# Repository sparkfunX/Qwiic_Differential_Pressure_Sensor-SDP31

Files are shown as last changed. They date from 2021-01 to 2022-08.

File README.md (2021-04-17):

SparkX Differential Pressure Sensor - SDP31 (Qwiic)
===================================================

SparkX Qwiic Differential Pressure Sensor SDP31 (SPX-17874) (https://www.sparkfun.com/products/17874)

[*SparkX Differential Pressure Sensor - SDP31 (Qwiic) (SPX-17874)*](https://www.sparkfun.com/products/17874)

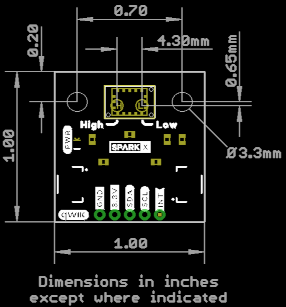
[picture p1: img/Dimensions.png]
SparkX Differential Pressure Sensor - SDP31


The SDP3x sensor family is Sensirion’s series of small differential pressure sensors designed for high-volume applications
where size is a key requirement. It builds on the next generation CMOSens® sensor chip that is at the heart of Sensirion’s
new differential pressure and flow sensing platform.

The digital SDP31 sensor features fast measurement speed, excellent accuracy and long-term stability and has no zero-point
drift. Furthermore, it is reflow solderable and provides extended functionality, such as smart averaging, multiple temperature
compensation modes, configurable I2C address and interrupts.

Able to measure differential pressures in the range +/- 500 Pascals (+/- 0.005 Atm), the SDP31 is ideally suited to air flow rate
and air speed measurement. Need an air speed indicator for your drone or model aircraft? This could be the sensor for you!

Repository Contents
-------------------
* **/Documents** - datasheets etc.
* **/Hardware** - Eagle design files (.brd, .sch)

Documentation
--------------
* **[SDP3X Arduino Library](https://github.com/sparkfun/SparkFun_SDP3x_Arduino_Library)** - Arduino library for the SparkFun Differential Pressure Sensor - SDP31.
* **[Hookup Guide]()** - Basic hookup guide for the SparkX Differential Pressure Sensor - SDP31.

Product Versions
----------------
* [SPX-17874](https://www.sparkfun.com/products/17874) - Original SparkX Release.

License Information
-------------------

This product is _**open source**_!

Please review the LICENSE.md file for license information.

If you have any questions or concerns on licensing, please contact technical support on our [SparkFun forums](https://forum.sparkfun.com/viewforum.php?f=152).

Distributed as-is; no warranty is given.

- Your friends at SparkFun.

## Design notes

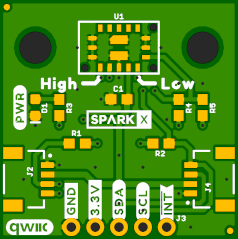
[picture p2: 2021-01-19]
img/Top.png

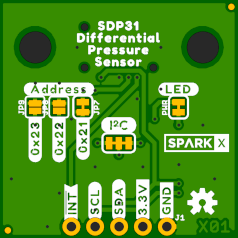
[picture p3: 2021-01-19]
img/Bottom.png

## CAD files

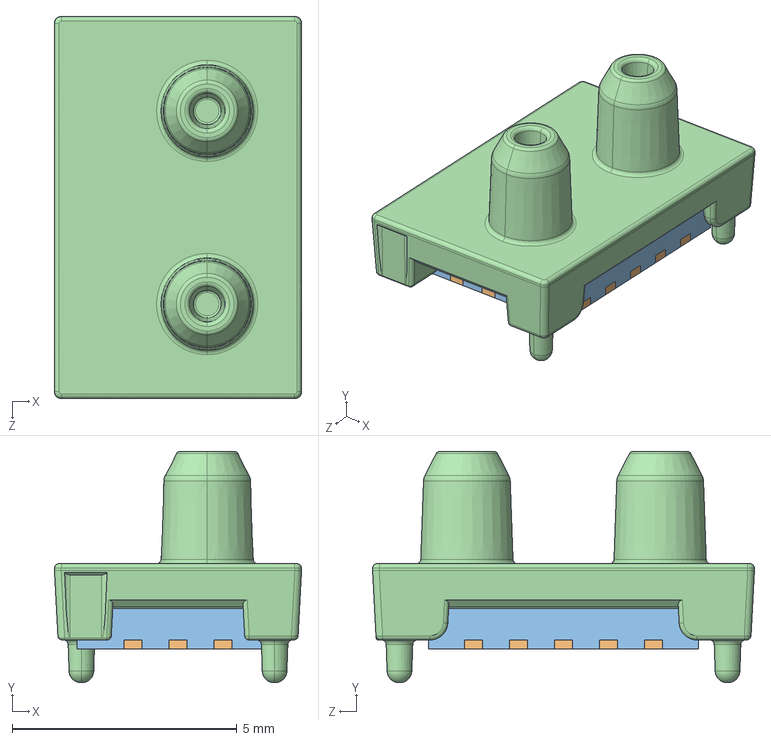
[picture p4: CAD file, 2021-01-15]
Documents/Sensirion_Differential_Pressure_Sensors_SDP3x_STEP_file.step
5.50 x 5.15 x 8.50 mm

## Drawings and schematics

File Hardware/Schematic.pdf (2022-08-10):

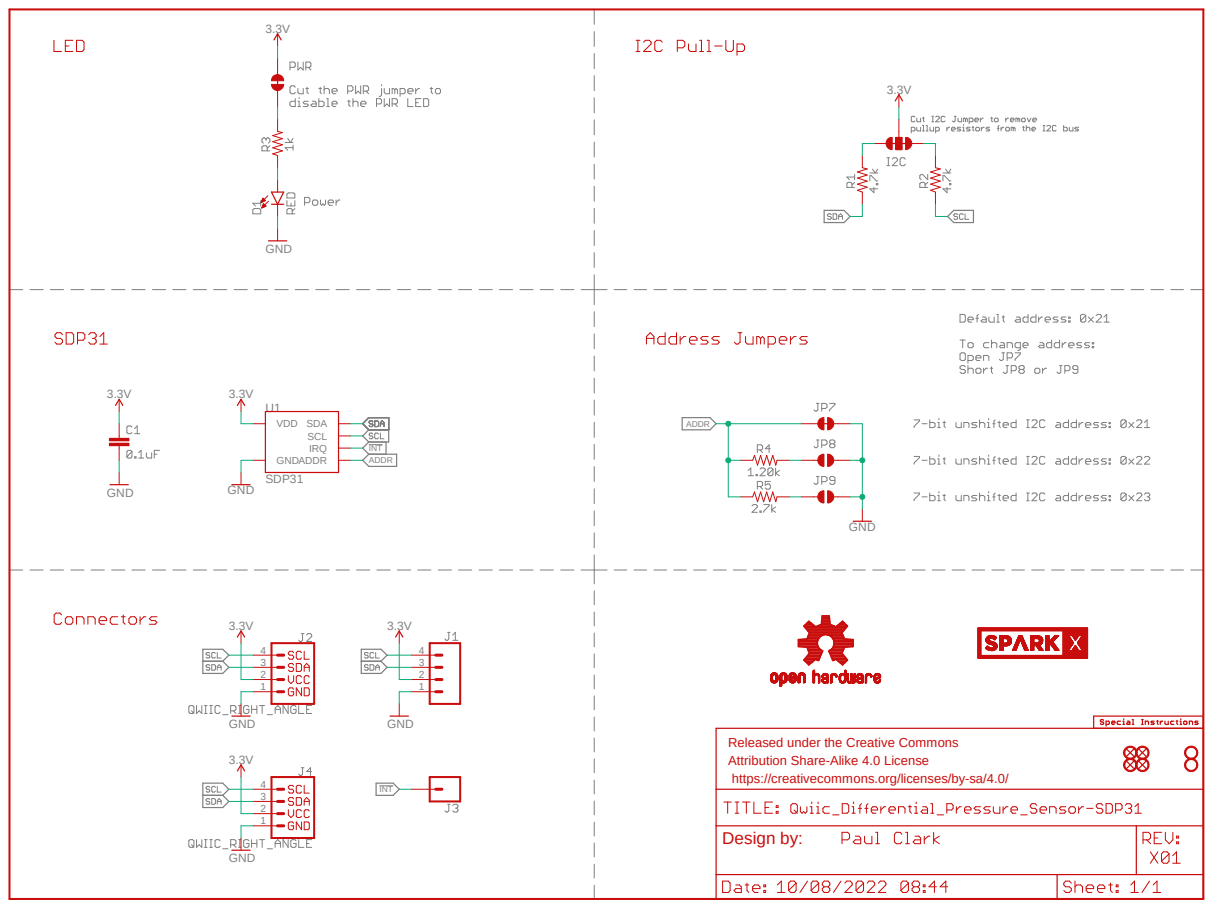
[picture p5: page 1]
GND; SDP31; VDD; SDA SCL IRQ; ADDR U1; INT; ADDR; Design by:

Released under the Creative Commons
Attribution Share-Alike 4.0 License
https://creativecommons.org/licenses/by-sa/4.0/

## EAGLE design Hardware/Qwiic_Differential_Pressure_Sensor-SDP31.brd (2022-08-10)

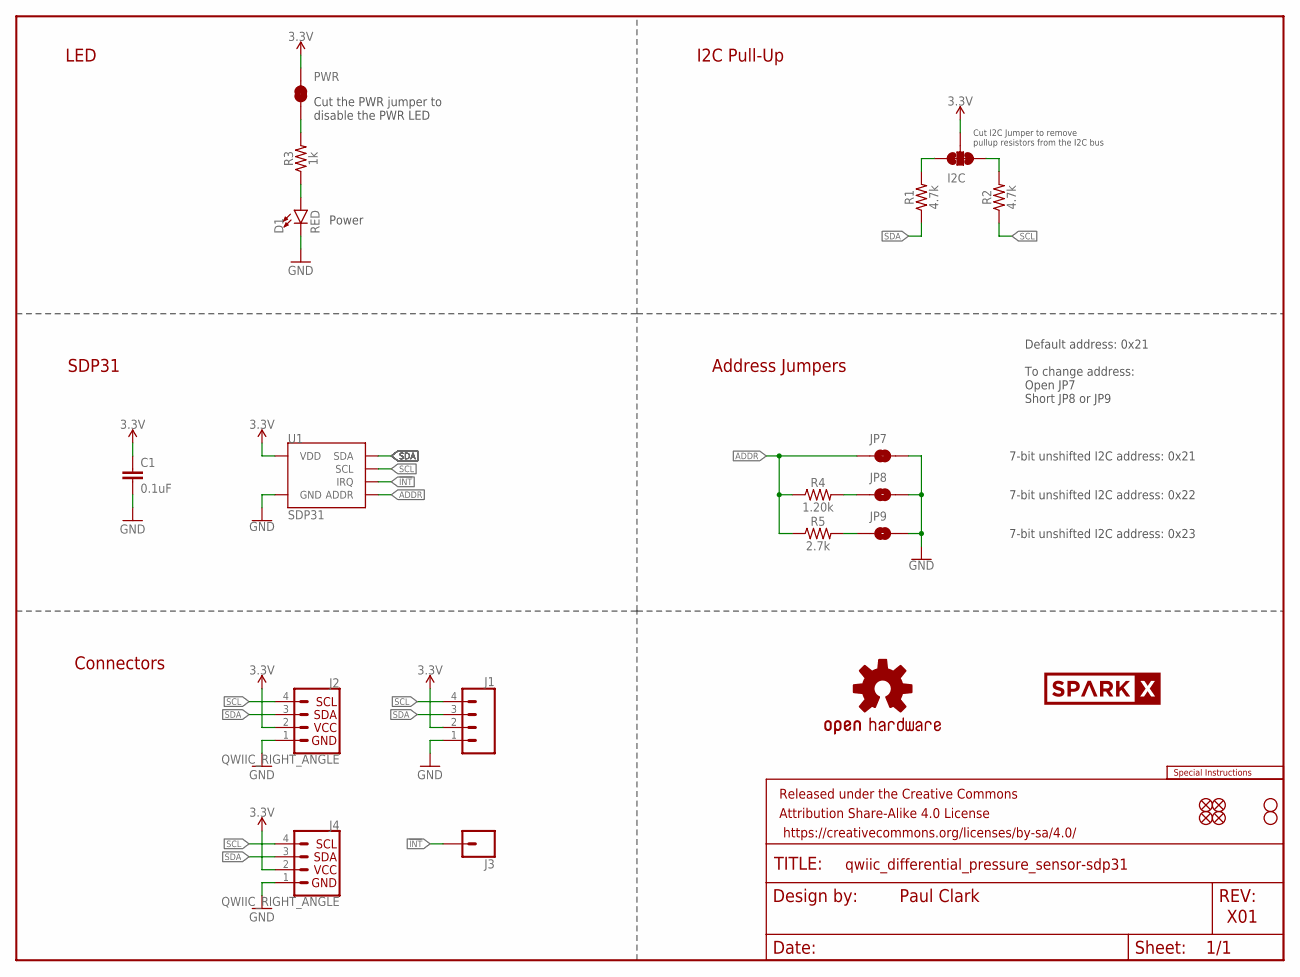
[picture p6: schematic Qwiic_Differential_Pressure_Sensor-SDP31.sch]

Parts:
C1: 0.1uF; 0603
D1: RED; LED-0603
FRAME1: FRAME-LETTER; CREATIVE_COMMONS
I2C: JUMPER-SMT_3_2-NC_TRACE_SILK; SMT-JUMPER_3_2-NC_TRACE_SILK
J1: CONN_041X04_NO_SILK; 1X04_NO_SILK
J2, J4: QWIIC_RIGHT_ANGLE; JST04_1MM_RA
J3: CONN_01PTH_NO_SILK_YES_STOP; 1X01_NO_SILK
JP1, JP2, JP5, JP6: FIDUCIALUFIDUCIAL; FIDUCIAL-MICRO
JP3, JP4: STAND-OFF
JP7: JUMPER-SMT_2_NC_TRACE_SILK; SMT-JUMPER_2_NC_TRACE_SILK
JP8, JP9: JUMPER-SMT_2_NO_SILK; SMT-JUMPER_2_NO_SILK
LOGO1: SPECIAL_INSTRUCTIONS-ORDERING; ORDERING_INSTRUCTIONS
LOGO5: OSHW-LOGOS; OSHW-LOGO-S
PWR: JUMPER-SMT_2_NC_TRACE_SILK; SMT-JUMPER_2_NC_TRACE_SILK
R1, R2: 4.7k; 0603
R3: 1k; 0603
R4: 1.20k; 0603
R5: 2.7k; 0603
U1: SDP31; SDP3X
U$18: SPARKX-LOGO3; SPARKX-SMALL

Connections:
3.3V: C1.1, I2C.2, J1.2, J2.2, J4.2, PWR.2, U1.7 (VDD)
!INT!: J3.1, U1.4 (IRQ)
ADDR: JP7.1, R4.1, R5.1, U1.9 (ADDR)
GND: C1.2, D1.C, J1.1, J2.1, J4.1, JP7.2, JP8.2, JP9.2, U1.1 (GND), U1.2 (GND), U1.3 (GND), U1.6 (GND), U1.10 (GND), U1.11 (GND), U1.DIEPAD1 (GND), U1.DIEPAD2 (GND)
unnamed: PWR.1, R3.2
unnamed: I2C.3, R1.2
unnamed: D1.A, R3.1
unnamed: I2C.1, R2.2
unnamed: JP8.1, R4.2
unnamed: JP9.1, R5.2
SCL: J1.4, J2.4, J4.4, R2.1, U1.5 (SCL)
SDA: J1.3, J2.3, J4.3, R1.1, U1.8 (SDA)

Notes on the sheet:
Paul Clark
X01
7-bit unshifted I2C address: 0x21
Power
I2C Pull-Up
SDP31
Connectors
Cut the PWR jumper to disable the PWR LED
Cut I2C Jumper to remove pullup resistors from the I2C bus
LED
Address Jumpers
7-bit unshifted I2C address: 0x22
7-bit unshifted I2C address: 0x23
Default address: 0x21 To change address: Open JP7 Short JP8 or JP9

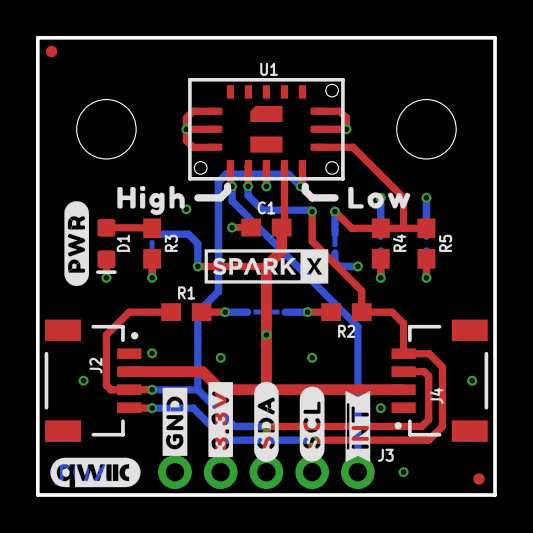
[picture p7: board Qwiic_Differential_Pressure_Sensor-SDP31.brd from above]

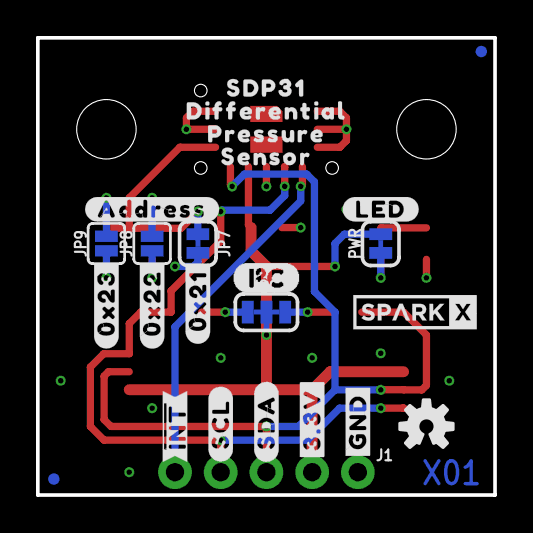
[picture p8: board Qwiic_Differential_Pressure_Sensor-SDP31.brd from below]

Board: 4 copper layers, 25.4 x 25.4 mm, 52 parts (25 on the bottom side), 12 nets.

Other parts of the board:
U$1, U$33: #GND#0
U$2, U$34: #3#3V#0
U$3, U$35: #SDA#0
U$4, U$36: #SCL#0
U$5, U$6: ##INT##0
U$7: #0X21#0
U$8: #0X22#0
U$9: #0X23#0
U$10: DIFFERENTIAL0
U$11: PRESSURE0
U$12: SENSOR0
U$13: SDP310
U$14: #LED#0
U$15: I2C
U$16: QWIIC_5MM
U$17: HIGH0
U$19: LOW0
U$20: SPARKX-LOGO3; SPARKX-SMALL
U$21: #ADDRESS#0
U$32: #PWR#0

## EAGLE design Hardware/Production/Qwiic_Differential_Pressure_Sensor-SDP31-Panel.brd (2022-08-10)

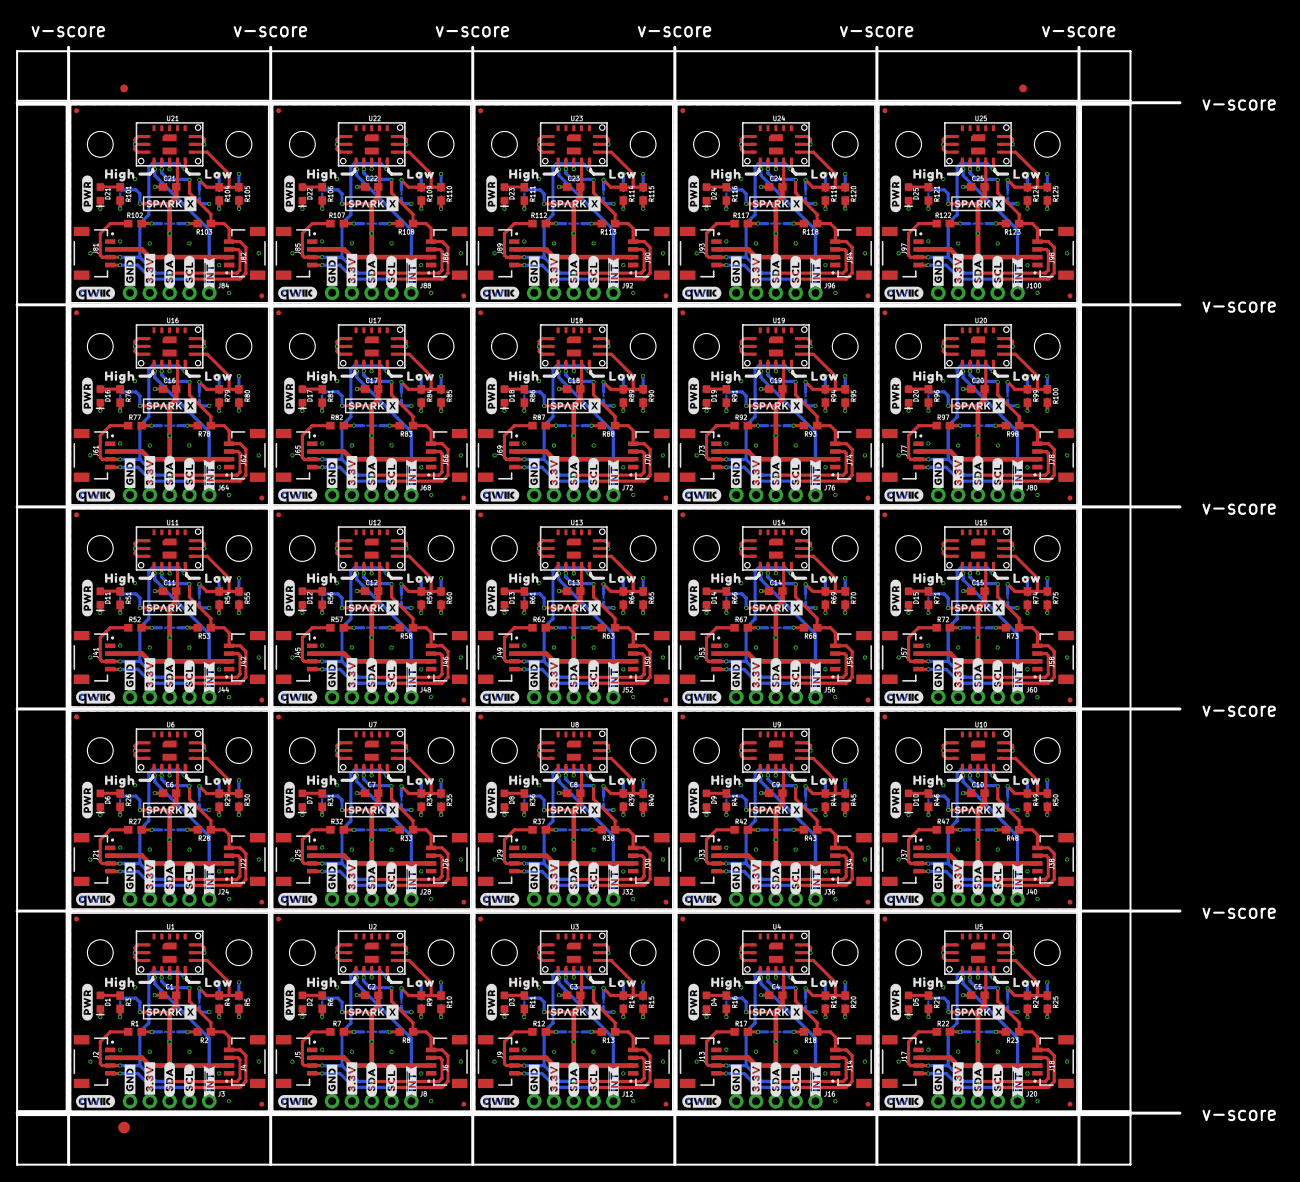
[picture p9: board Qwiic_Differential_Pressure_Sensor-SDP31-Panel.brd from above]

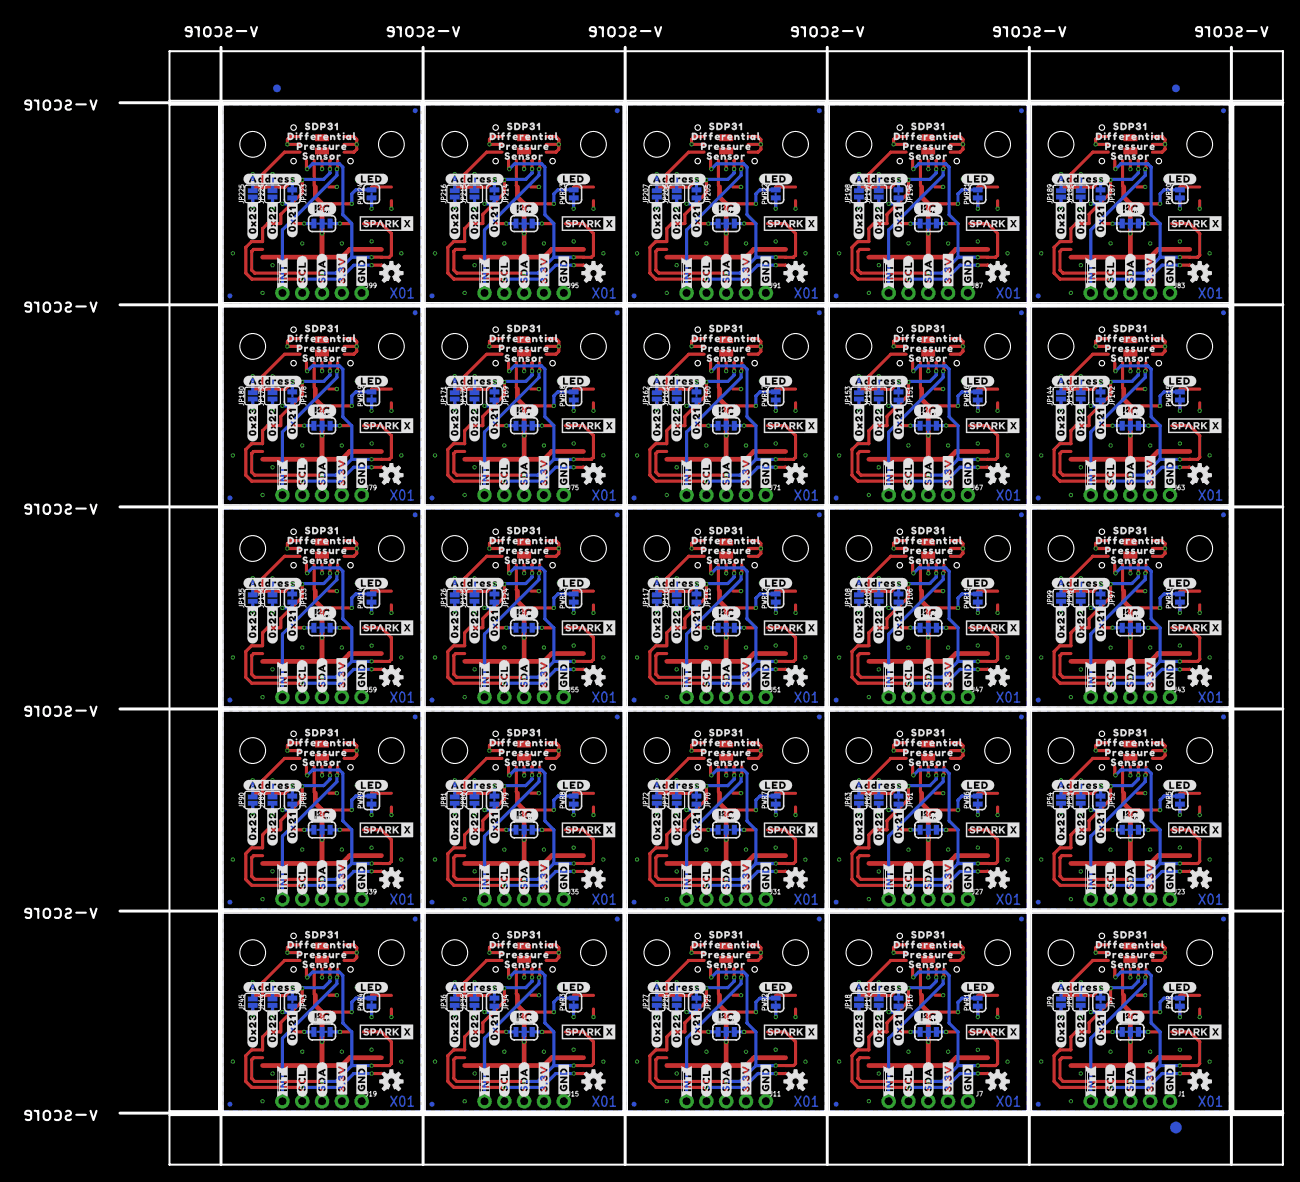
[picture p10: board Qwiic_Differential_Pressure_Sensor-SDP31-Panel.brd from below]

Board: 4 copper layers, 149.1 x 143.3 mm, 1256 parts (628 on the bottom side), 300 nets.

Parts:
C1, C2, C3, C4, C5, C6, C7, C8, C9, C10, C11, C12, C13, C14, C15, C16, C17, C18, C19, C20, C21, C22, C23, C24, C25: 0.1uF; 0603
D1, D2, D3, D4, D5, D6, D7, D8, D9, D10, D11, D12, D13, D14, D15, D16, D17, D18, D19, D20, D21, D22, D23, D24, D25: RED; LED-0603
E$1, E$2, E$3, E$4: FIDUCIAL-1X2
E$5, E$6: FIDUCIAL-1.5X3
I2C, I2C1, I2C2, I2C3, I2C4, I2C5, I2C6, I2C7, I2C8, I2C9, I2C10, I2C11, I2C12, I2C13, I2C14, I2C15, I2C16, I2C17, I2C18, I2C19, I2C20, I2C21, I2C22, I2C23, I2C24: JUMPER-SMT_3_2-NC_TRACE_SILK; SMT-JUMPER_3_2-NC_TRACE_SILK
J1, J7, J11, J15, J19, J23, J27, J31, J35, J39, J43, J47, J51, J55, J59, J63, J67, J71, J75, J79, J83, J87, J91, J95, J99: 1X04_NO_SILK
J2, J4, J5, J6, J9, J10, J13, J14, J17, J18, J21, J22, J25, J26, J29, J30, J33, J34, J37, J38, J41, J42, J45, J46, J49, J50, J53, J54, J57, J58, J61, J62, J65, J66, J69, J70, J73, J74, J77, J78, J81, J82, J85, J86, J89, J90, J93, J94, J97, J98: QWIIC_RIGHT_ANGLE; JST04_1MM_RA
J3, J8, J12, J16, J20, J24, J28, J32, J36, J40, J44, J48, J52, J56, J60, J64, J68, J72, J76, J80, J84, J88, J92, J96, J100: 1X01_NO_SILK
JP1, JP2, JP5, JP6, JP12, JP13, JP14, JP15, JP21, JP22, JP23, JP24, JP30, JP31, JP32, JP33, JP39, JP40, JP41, JP42, JP48, JP49, JP50, JP51, JP57, JP58, JP59, JP60, JP66, JP67, JP68, JP69, JP75, JP76, JP77, JP78, JP84, JP85, JP86, JP87, JP93, JP94, JP95, JP96, JP102, JP103, JP104, JP105, JP111, JP112, JP113, JP114, JP120, JP121, JP122, JP123, JP129, JP130, JP131, JP132, JP138, JP139, JP140, JP141, JP147, JP148, JP149, JP150, JP156, JP157, JP158, JP159, JP165, JP166, JP167, JP168, JP174, JP175, JP176, JP177, JP183, JP184, JP185, JP186, JP192, JP193, JP194, JP195, JP201, JP202, JP203, JP204, JP210, JP211, JP212, JP213, JP219, JP220, JP221, JP222: FIDUCIALUFIDUCIAL; FIDUCIAL-MICRO
JP3, JP4, JP10, JP11, JP19, JP20, JP28, JP29, JP37, JP38, JP46, JP47, JP55, JP56, JP64, JP65, JP73, JP74, JP82, JP83, JP91, JP92, JP100, JP101, JP109, JP110, JP118, JP119, JP127, JP128, JP136, JP137, JP145, JP146, JP154, JP155, JP163, JP164, JP172, JP173, JP181, JP182, JP190, JP191, JP199, JP200, JP208, JP209, JP217, JP218: STAND-OFF
JP7, JP16, JP25, JP34, JP43, JP52, JP61, JP70, JP79, JP88, JP97, JP106, JP115, JP124, JP133, JP142, JP151, JP160, JP169, JP178, JP187, JP196, JP205, JP214, JP223: JUMPER-SMT_2_NC_TRACE_SILK; SMT-JUMPER_2_NC_TRACE_SILK
JP8, JP9, JP17, JP18, JP26, JP27, JP35, JP36, JP44, JP45, JP53, JP54, JP62, JP63, JP71, JP72, JP80, JP81, JP89, JP90, JP98, JP99, JP107, JP108, JP116, JP117, JP125, JP126, JP134, JP135, JP143, JP144, JP152, JP153, JP161, JP162, JP170, JP171, JP179, JP180, JP188, JP189, JP197, JP198, JP206, JP207, JP215, JP216, JP224, JP225: JUMPER-SMT_2_NO_SILK; SMT-JUMPER_2_NO_SILK
LOGO1, LOGO2, LOGO3, LOGO4, LOGO5, LOGO6, LOGO7, LOGO8, LOGO9, LOGO10, LOGO11, LOGO12, LOGO13, LOGO14, LOGO15, LOGO16, LOGO17, LOGO18, LOGO19, LOGO20, LOGO21, LOGO22, LOGO23, LOGO24, LOGO25: OSHW-LOGOS; OSHW-LOGO-S
PWR, PWR1, PWR2, PWR3, PWR4, PWR5, PWR6, PWR7, PWR8, PWR9, PWR10, PWR11, PWR12, PWR13, PWR14, PWR15, PWR16, PWR17, PWR18, PWR19, PWR20, PWR21, PWR22, PWR23, PWR24: JUMPER-SMT_2_NC_TRACE_SILK; SMT-JUMPER_2_NC_TRACE_SILK
R1, R2, R7, R8, R12, R13, R17, R18, R22, R23, R27, R28, R32, R33, R37, R38, R42, R43, R47, R48, R52, R53, R57, R58, R62, R63, R67, R68, R72, R73, R77, R78, R82, R83, R87, R88, R92, R93, R97, R98, R102, R103, R107, R108, R112, R113, R117, R118, R122, R123: 4.7k; 0603
R3, R6, R11, R16, R21, R26, R31, R36, R41, R46, R51, R56, R61, R66, R71, R76, R81, R86, R91, R96, R101, R106, R111, R116, R121: 1k; 0603
R4, R9, R14, R19, R24, R29, R34, R39, R44, R49, R54, R59, R64, R69, R74, R79, R84, R89, R94, R99, R104, R109, R114, R119, R124: 1.20k; 0603
R5, R10, R15, R20, R25, R30, R35, R40, R45, R50, R55, R60, R65, R70, R75, R80, R85, R90, R95, R100, R105, R110, R115, R120, R125: 2.7k; 0603
U1, U2, U3, U4, U5, U6, U7, U8, U9, U10, U11, U12, U13, U14, U15, U16, U17, U18, U19, U20, U21, U22, U23, U24, U25: SDP31; SDP3X
U$1, U$26, U$30, U$33, U$57, U$61, U$83, U$87, U$109, U$113, U$135, U$139, U$161, U$165, U$187, U$191, U$213, U$217, U$239, U$243, U$265, U$269, U$291, U$295, U$317, U$321, U$343, U$347, U$369, U$373, U$395, U$399, U$421, U$425, U$447, U$451, U$473, U$477, U$499, U$503, U$525, U$529, U$551, U$555, U$577, U$581, U$603, U$607, U$629, U$633: #GND#0
U$2, U$27, U$31, U$34, U$58, U$62, U$84, U$88, U$110, U$114, U$136, U$140, U$162, U$166, U$188, U$192, U$214, U$218, U$240, U$244, U$266, U$270, U$292, U$296, U$318, U$322, U$344, U$348, U$370, U$374, U$396, U$400, U$422, U$426, U$448, U$452, U$474, U$478, U$500, U$504, U$526, U$530, U$552, U$556, U$578, U$582, U$604, U$608, U$630, U$634: #3#3V#0
U$3, U$28, U$35, U$37, U$59, U$63, U$85, U$89, U$111, U$115, U$137, U$141, U$163, U$167, U$189, U$193, U$215, U$219, U$241, U$245, U$267, U$271, U$293, U$297, U$319, U$323, U$345, U$349, U$371, U$375, U$397, U$401, U$423, U$427, U$449, U$453, U$475, U$479, U$501, U$505, U$527, U$531, U$553, U$557, U$579, U$583, U$605, U$609, U$631, U$635: #SDA#0
U$4, U$29, U$36, U$38, U$60, U$64, U$86, U$90, U$112, U$116, U$138, U$142, U$164, U$168, U$190, U$194, U$216, U$220, U$242, U$246, U$268, U$272, U$294, U$298, U$320, U$324, U$346, U$350, U$372, U$376, U$398, U$402, U$424, U$428, U$450, U$454, U$476, U$480, U$502, U$506, U$528, U$532, U$554, U$558, U$580, U$584, U$606, U$610, U$632, U$636: #SCL#0
U$5, U$6, U$50, U$51, U$76, U$77, U$102, U$103, U$128, U$129, U$154, U$155, U$180, U$181, U$206, U$207, U$232, U$233, U$258, U$259, U$284, U$285, U$310, U$311, U$336, U$337, U$362, U$363, U$388, U$389, U$414, U$415, U$440, U$441, U$466, U$467, U$492, U$493, U$518, U$519, U$544, U$545, U$570, U$571, U$596, U$597, U$622, U$623, U$648, U$649: ##INT##0
U$7, U$39, U$65, U$91, U$117, U$143, U$169, U$195, U$221, U$247, U$273, U$299, U$325, U$351, U$377, U$403, U$429, U$455, U$481, U$507, U$533, U$559, U$585, U$611, U$637: #0X21#0
U$8, U$40, U$66, U$92, U$118, U$144, U$170, U$196, U$222, U$248, U$274, U$300, U$326, U$352, U$378, U$404, U$430, U$456, U$482, U$508, U$534, U$560, U$586, U$612, U$638: #0X22#0
U$9, U$41, U$67, U$93, U$119, U$145, U$171, U$197, U$223, U$249, U$275, U$301, U$327, U$353, U$379, U$405, U$431, U$457, U$483, U$509, U$535, U$561, U$587, U$613, U$639: #0X23#0
U$10, U$42, U$68, U$94, U$120, U$146, U$172, U$198, U$224, U$250, U$276, U$302, U$328, U$354, U$380, U$406, U$432, U$458, U$484, U$510, U$536, U$562, U$588, U$614, U$640: DIFFERENTIAL0
U$11, U$43, U$69, U$95, U$121, U$147, U$173, U$199, U$225, U$251, U$277, U$303, U$329, U$355, U$381, U$407, U$433, U$459, U$485, U$511, U$537, U$563, U$589, U$615, U$641: PRESSURE0
U$12, U$44, U$70, U$96, U$122, U$148, U$174, U$200, U$226, U$252, U$278, U$304, U$330, U$356, U$382, U$408, U$434, U$460, U$486, U$512, U$538, U$564, U$590, U$616, U$642: SENSOR0
U$13, U$45, U$71, U$97, U$123, U$149, U$175, U$201, U$227, U$253, U$279, U$305, U$331, U$357, U$383, U$409, U$435, U$461, U$487, U$513, U$539, U$565, U$591, U$617, U$643: SDP310
U$14, U$46, U$72, U$98, U$124, U$150, U$176, U$202, U$228, U$254, U$280, U$306, U$332, U$358, U$384, U$410, U$436, U$462, U$488, U$514, U$540, U$566, U$592, U$618, U$644: #LED#0
U$15, U$22, U$53, U$79, U$105, U$131, U$157, U$183, U$209, U$235, U$261, U$287, U$313, U$339, U$365, U$391, U$417, U$443, U$469, U$495, U$521, U$547, U$573, U$599, U$625: I2C
U$16, U$23, U$54, U$80, U$106, U$132, U$158, U$184, U$210, U$236, U$262, U$288, U$314, U$340, U$366, U$392, U$418, U$444, U$470, U$496, U$522, U$548, U$574, U$600, U$626: QWIIC_5MM
U$17, U$47, U$73, U$99, U$125, U$151, U$177, U$203, U$229, U$255, U$281, U$307, U$333, U$359, U$385, U$411, U$437, U$463, U$489, U$515, U$541, U$567, U$593, U$619, U$645: HIGH0
U$18, U$20, U$24, U$49, U$55, U$75, U$81, U$101, U$107, U$127, U$133, U$153, U$159, U$179, U$185, U$205, U$211, U$231, U$237, U$257, U$263, U$283, U$289, U$309, U$315, U$335, U$341, U$361, U$367, U$387, U$393, U$413, U$419, U$439, U$445, U$465, U$471, U$491, U$497, U$517, U$523, U$543, U$549, U$569, U$575, U$595, U$601, U$621, U$627, U$647: SPARKX-LOGO3; SPARKX-SMALL
U$19, U$48, U$74, U$100, U$126, U$152, U$178, U$204, U$230, U$256, U$282, U$308, U$334, U$360, U$386, U$412, U$438, U$464, U$490, U$516, U$542, U$568, U$594, U$620, U$646: LOW0
U$21, U$52, U$78, U$104, U$130, U$156, U$182, U$208, U$234, U$260, U$286, U$312, U$338, U$364, U$390, U$416, U$442, U$468, U$494, U$520, U$546, U$572, U$598, U$624, U$650: #ADDRESS#0
U$25, U$32, U$56, U$82, U$108, U$134, U$160, U$186, U$212, U$238, U$264, U$290, U$316, U$342, U$368, U$394, U$420, U$446, U$472, U$498, U$524, U$550, U$576, U$602, U$628: #PWR#0

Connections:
3.3V: C1.1, I2C.2, J1.2, J2.2, J4.2, PWR.2, U1.7
3.3V1: C2.1, I2C1.2, J5.2, J6.2, J7.2, PWR1.2, U2.7
3.3V2: C3.1, I2C2.2, J9.2, J10.2, J11.2, PWR2.2, U3.7
3.3V3: C4.1, I2C3.2, J13.2, J14.2, J15.2, PWR3.2, U4.7
3.3V4: C5.1, I2C4.2, J17.2, J18.2, J19.2, PWR4.2, U5.7
3.3V5: C6.1, I2C5.2, J21.2, J22.2, J23.2, PWR5.2, U6.7
3.3V6: C7.1, I2C6.2, J25.2, J26.2, J27.2, PWR6.2, U7.7
3.3V7: C8.1, I2C7.2, J29.2, J30.2, J31.2, PWR7.2, U8.7
3.3V8: C9.1, I2C8.2, J33.2, J34.2, J35.2, PWR8.2, U9.7
3.3V9: C10.1, I2C9.2, J37.2, J38.2, J39.2, PWR9.2, U10.7
3.3V10: C11.1, I2C10.2, J41.2, J42.2, J43.2, PWR10.2, U11.7
3.3V11: C12.1, I2C11.2, J45.2, J46.2, J47.2, PWR11.2, U12.7
3.3V12: C13.1, I2C12.2, J49.2, J50.2, J51.2, PWR12.2, U13.7
3.3V13: C14.1, I2C13.2, J53.2, J54.2, J55.2, PWR13.2, U14.7
3.3V14: C15.1, I2C14.2, J57.2, J58.2, J59.2, PWR14.2, U15.7
3.3V15: C16.1, I2C15.2, J61.2, J62.2, J63.2, PWR15.2, U16.7
3.3V16: C17.1, I2C16.2, J65.2, J66.2, J67.2, PWR16.2, U17.7
3.3V17: C18.1, I2C17.2, J69.2, J70.2, J71.2, PWR17.2, U18.7
3.3V18: C19.1, I2C18.2, J73.2, J74.2, J75.2, PWR18.2, U19.7
3.3V19: C20.1, I2C19.2, J77.2, J78.2, J79.2, PWR19.2, U20.7
3.3V20: C21.1, I2C20.2, J81.2, J82.2, J83.2, PWR20.2, U21.7
3.3V21: C22.1, I2C21.2, J85.2, J86.2, J87.2, PWR21.2, U22.7
3.3V22: C23.1, I2C22.2, J89.2, J90.2, J91.2, PWR22.2, U23.7
3.3V23: C24.1, I2C23.2, J93.2, J94.2, J95.2, PWR23.2, U24.7
3.3V24: C25.1, I2C24.2, J97.2, J98.2, J99.2, PWR24.2, U25.7
!INT!: J3.1, U1.4
!INT!1: J8.1, U2.4
!INT!2: J12.1, U3.4
!INT!3: J16.1, U4.4
!INT!4: J20.1, U5.4
!INT!5: J24.1, U6.4
!INT!6: J28.1, U7.4
!INT!7: J32.1, U8.4
!INT!8: J36.1, U9.4
!INT!9: J40.1, U10.4
!INT!10: J44.1, U11.4
!INT!11: J48.1, U12.4
!INT!12: J52.1, U13.4
!INT!13: J56.1, U14.4
!INT!14: J60.1, U15.4
!INT!15: J64.1, U16.4
!INT!16: J68.1, U17.4
!INT!17: J72.1, U18.4
!INT!18: J76.1, U19.4
!INT!19: J80.1, U20.4
!INT!20: J84.1, U21.4
!INT!21: J88.1, U22.4
!INT!22: J92.1, U23.4
!INT!23: J96.1, U24.4
!INT!24: J100.1, U25.4
ADDR: JP7.1, R4.1, R5.1, U1.9
ADDR1: JP16.1, R9.1, R10.1, U2.9
ADDR2: JP25.1, R14.1, R15.1, U3.9
ADDR3: JP34.1, R19.1, R20.1, U4.9
ADDR4: JP43.1, R24.1, R25.1, U5.9
ADDR5: JP52.1, R29.1, R30.1, U6.9
ADDR6: JP61.1, R34.1, R35.1, U7.9
ADDR7: JP70.1, R39.1, R40.1, U8.9
ADDR8: JP79.1, R44.1, R45.1, U9.9
ADDR9: JP88.1, R49.1, R50.1, U10.9
ADDR10: JP97.1, R54.1, R55.1, U11.9
ADDR11: JP106.1, R59.1, R60.1, U12.9
ADDR12: JP115.1, R64.1, R65.1, U13.9
ADDR13: JP124.1, R69.1, R70.1, U14.9
ADDR14: JP133.1, R74.1, R75.1, U15.9
ADDR15: JP142.1, R79.1, R80.1, U16.9
ADDR16: JP151.1, R84.1, R85.1, U17.9
ADDR17: JP160.1, R89.1, R90.1, U18.9
ADDR18: JP169.1, R94.1, R95.1, U19.9
ADDR19: JP178.1, R99.1, R100.1, U20.9
ADDR20: JP187.1, R104.1, R105.1, U21.9
ADDR21: JP196.1, R109.1, R110.1, U22.9
ADDR22: JP205.1, R114.1, R115.1, U23.9
ADDR23: JP214.1, R119.1, R120.1, U24.9
ADDR24: JP223.1, R124.1, R125.1, U25.9
GND: C1.2, D1.C, J1.1, J2.1, J4.1, JP7.2, JP8.2, JP9.2, U1.1, U1.2, U1.3, U1.6, U1.10, U1.11, U1.DIEPAD1, U1.DIEPAD2
GND1: C2.2, D2.C, J5.1, J6.1, J7.1, JP16.2, JP17.2, JP18.2, U2.1, U2.2, U2.3, U2.6, U2.10, U2.11, U2.DIEPAD1, U2.DIEPAD2
GND2: C3.2, D3.C, J9.1, J10.1, J11.1, JP25.2, JP26.2, JP27.2, U3.1, U3.2, U3.3, U3.6, U3.10, U3.11, U3.DIEPAD1, U3.DIEPAD2
GND3: C4.2, D4.C, J13.1, J14.1, J15.1, JP34.2, JP35.2, JP36.2, U4.1, U4.2, U4.3, U4.6, U4.10, U4.11, U4.DIEPAD1, U4.DIEPAD2
GND4: C5.2, D5.C, J17.1, J18.1, J19.1, JP43.2, JP44.2, JP45.2, U5.1, U5.2, U5.3, U5.6, U5.10, U5.11, U5.DIEPAD1, U5.DIEPAD2
GND5: C6.2, D6.C, J21.1, J22.1, J23.1, JP52.2, JP53.2, JP54.2, U6.1, U6.2, U6.3, U6.6, U6.10, U6.11, U6.DIEPAD1, U6.DIEPAD2
GND6: C7.2, D7.C, J25.1, J26.1, J27.1, JP61.2, JP62.2, JP63.2, U7.1, U7.2, U7.3, U7.6, U7.10, U7.11, U7.DIEPAD1, U7.DIEPAD2
GND7: C8.2, D8.C, J29.1, J30.1, J31.1, JP70.2, JP71.2, JP72.2, U8.1, U8.2, U8.3, U8.6, U8.10, U8.11, U8.DIEPAD1, U8.DIEPAD2
GND8: C9.2, D9.C, J33.1, J34.1, J35.1, JP79.2, JP80.2, JP81.2, U9.1, U9.2, U9.3, U9.6, U9.10, U9.11, U9.DIEPAD1, U9.DIEPAD2
GND9: C10.2, D10.C, J37.1, J38.1, J39.1, JP88.2, JP89.2, JP90.2, U10.1, U10.2, U10.3, U10.6, U10.10, U10.11, U10.DIEPAD1, U10.DIEPAD2
GND10: C11.2, D11.C, J41.1, J42.1, J43.1, JP97.2, JP98.2, JP99.2, U11.1, U11.2, U11.3, U11.6, U11.10, U11.11, U11.DIEPAD1, U11.DIEPAD2
GND11: C12.2, D12.C, J45.1, J46.1, J47.1, JP106.2, JP107.2, JP108.2, U12.1, U12.2, U12.3, U12.6, U12.10, U12.11, U12.DIEPAD1, U12.DIEPAD2
GND12: C13.2, D13.C, J49.1, J50.1, J51.1, JP115.2, JP116.2, JP117.2, U13.1, U13.2, U13.3, U13.6, U13.10, U13.11, U13.DIEPAD1, U13.DIEPAD2
GND13: C14.2, D14.C, J53.1, J54.1, J55.1, JP124.2, JP125.2, JP126.2, U14.1, U14.2, U14.3, U14.6, U14.10, U14.11, U14.DIEPAD1, U14.DIEPAD2
GND14: C15.2, D15.C, J57.1, J58.1, J59.1, JP133.2, JP134.2, JP135.2, U15.1, U15.2, U15.3, U15.6, U15.10, U15.11, U15.DIEPAD1, U15.DIEPAD2
GND15: C16.2, D16.C, J61.1, J62.1, J63.1, JP142.2, JP143.2, JP144.2, U16.1, U16.2, U16.3, U16.6, U16.10, U16.11, U16.DIEPAD1, U16.DIEPAD2
GND16: C17.2, D17.C, J65.1, J66.1, J67.1, JP151.2, JP152.2, JP153.2, U17.1, U17.2, U17.3, U17.6, U17.10, U17.11, U17.DIEPAD1, U17.DIEPAD2
GND17: C18.2, D18.C, J69.1, J70.1, J71.1, JP160.2, JP161.2, JP162.2, U18.1, U18.2, U18.3, U18.6, U18.10, U18.11, U18.DIEPAD1, U18.DIEPAD2
GND18: C19.2, D19.C, J73.1, J74.1, J75.1, JP169.2, JP170.2, JP171.2, U19.1, U19.2, U19.3, U19.6, U19.10, U19.11, U19.DIEPAD1, U19.DIEPAD2
GND19: C20.2, D20.C, J77.1, J78.1, J79.1, JP178.2, JP179.2, JP180.2, U20.1, U20.2, U20.3, U20.6, U20.10, U20.11, U20.DIEPAD1, U20.DIEPAD2
GND20: C21.2, D21.C, J81.1, J82.1, J83.1, JP187.2, JP188.2, JP189.2, U21.1, U21.2, U21.3, U21.6, U21.10, U21.11, U21.DIEPAD1, U21.DIEPAD2
GND21: C22.2, D22.C, J85.1, J86.1, J87.1, JP196.2, JP197.2, JP198.2, U22.1, U22.2, U22.3, U22.6, U22.10, U22.11, U22.DIEPAD1, U22.DIEPAD2
GND22: C23.2, D23.C, J89.1, J90.1, J91.1, JP205.2, JP206.2, JP207.2, U23.1, U23.2, U23.3, U23.6, U23.10, U23.11, U23.DIEPAD1, U23.DIEPAD2
GND23: C24.2, D24.C, J93.1, J94.1, J95.1, JP214.2, JP215.2, JP216.2, U24.1, U24.2, U24.3, U24.6, U24.10, U24.11, U24.DIEPAD1, U24.DIEPAD2
GND24: C25.2, D25.C, J97.1, J98.1, J99.1, JP223.2, JP224.2, JP225.2, U25.1, U25.2, U25.3, U25.6, U25.10, U25.11, U25.DIEPAD1, U25.DIEPAD2
unnamed: PWR.1, R3.2
unnamed: I2C.3, R1.2
unnamed: D1.A, R3.1
unnamed: I2C.1, R2.2
unnamed: JP8.1, R4.2
unnamed: JP9.1, R5.2
unnamed: D2.A, R6.1
unnamed: PWR1.1, R6.2
unnamed: I2C1.3, R7.2
unnamed: I2C1.1, R8.2
unnamed: JP17.1, R9.2
unnamed: JP18.1, R10.2
unnamed: D3.A, R11.1
unnamed: PWR2.1, R11.2
unnamed: I2C2.3, R12.2
unnamed: I2C2.1, R13.2
unnamed: JP26.1, R14.2
unnamed: JP27.1, R15.2
unnamed: D4.A, R16.1
unnamed: PWR3.1, R16.2
unnamed: I2C3.3, R17.2
unnamed: I2C3.1, R18.2
unnamed: JP35.1, R19.2
unnamed: JP36.1, R20.2
unnamed: D5.A, R21.1
unnamed: PWR4.1, R21.2
unnamed: I2C4.3, R22.2
unnamed: I2C4.1, R23.2
unnamed: JP44.1, R24.2
unnamed: JP45.1, R25.2
unnamed: D6.A, R26.1
unnamed: PWR5.1, R26.2
unnamed: I2C5.3, R27.2
unnamed: I2C5.1, R28.2
unnamed: JP53.1, R29.2
unnamed: JP54.1, R30.2
unnamed: D7.A, R31.1
unnamed: PWR6.1, R31.2
unnamed: I2C6.3, R32.2
unnamed: I2C6.1, R33.2
unnamed: JP62.1, R34.2
unnamed: JP63.1, R35.2
unnamed: D8.A, R36.1
unnamed: PWR7.1, R36.2
unnamed: I2C7.3, R37.2
unnamed: I2C7.1, R38.2
unnamed: JP71.1, R39.2
unnamed: JP72.1, R40.2
unnamed: D9.A, R41.1
unnamed: PWR8.1, R41.2
unnamed: I2C8.3, R42.2
unnamed: I2C8.1, R43.2
unnamed: JP80.1, R44.2
unnamed: JP81.1, R45.2
unnamed: D10.A, R46.1
unnamed: PWR9.1, R46.2
unnamed: I2C9.3, R47.2
unnamed: I2C9.1, R48.2
unnamed: JP89.1, R49.2
unnamed: JP90.1, R50.2
unnamed: D11.A, R51.1
unnamed: PWR10.1, R51.2
unnamed: I2C10.3, R52.2
unnamed: I2C10.1, R53.2
unnamed: JP98.1, R54.2
unnamed: JP99.1, R55.2
unnamed: D12.A, R56.1
unnamed: PWR11.1, R56.2
unnamed: I2C11.3, R57.2
unnamed: I2C11.1, R58.2
unnamed: JP107.1, R59.2
unnamed: JP108.1, R60.2
unnamed: D13.A, R61.1
unnamed: PWR12.1, R61.2
unnamed: I2C12.3, R62.2
unnamed: I2C12.1, R63.2
unnamed: JP116.1, R64.2
unnamed: JP117.1, R65.2
unnamed: D14.A, R66.1
unnamed: PWR13.1, R66.2
unnamed: I2C13.3, R67.2
unnamed: I2C13.1, R68.2
unnamed: JP125.1, R69.2
unnamed: JP126.1, R70.2
unnamed: D15.A, R71.1
unnamed: PWR14.1, R71.2
unnamed: I2C14.3, R72.2
unnamed: I2C14.1, R73.2
unnamed: JP134.1, R74.2
unnamed: JP135.1, R75.2
unnamed: D16.A, R76.1
unnamed: PWR15.1, R76.2
unnamed: I2C15.3, R77.2
unnamed: I2C15.1, R78.2
unnamed: JP143.1, R79.2
unnamed: JP144.1, R80.2
unnamed: D17.A, R81.1
unnamed: PWR16.1, R81.2
unnamed: I2C16.3, R82.2
unnamed: I2C16.1, R83.2
unnamed: JP152.1, R84.2
unnamed: JP153.1, R85.2
unnamed: D18.A, R86.1
unnamed: PWR17.1, R86.2
unnamed: I2C17.3, R87.2
unnamed: I2C17.1, R88.2
unnamed: JP161.1, R89.2
unnamed: JP162.1, R90.2
unnamed: D19.A, R91.1
unnamed: PWR18.1, R91.2
unnamed: I2C18.3, R92.2
unnamed: I2C18.1, R93.2
unnamed: JP170.1, R94.2
unnamed: JP171.1, R95.2
unnamed: D20.A, R96.1
unnamed: PWR19.1, R96.2
unnamed: I2C19.3, R97.2
unnamed: I2C19.1, R98.2
unnamed: JP179.1, R99.2
unnamed: JP180.1, R100.2
unnamed: D21.A, R101.1
unnamed: PWR20.1, R101.2
unnamed: I2C20.3, R102.2
unnamed: I2C20.1, R103.2
unnamed: JP188.1, R104.2
unnamed: JP189.1, R105.2
unnamed: D22.A, R106.1
unnamed: PWR21.1, R106.2
unnamed: I2C21.3, R107.2
unnamed: I2C21.1, R108.2
unnamed: JP197.1, R109.2
unnamed: JP198.1, R110.2
unnamed: D23.A, R111.1
unnamed: PWR22.1, R111.2
unnamed: I2C22.3, R112.2
unnamed: I2C22.1, R113.2
unnamed: JP206.1, R114.2
unnamed: JP207.1, R115.2
unnamed: D24.A, R116.1
unnamed: PWR23.1, R116.2
unnamed: I2C23.3, R117.2
unnamed: I2C23.1, R118.2
unnamed: JP215.1, R119.2
unnamed: JP216.1, R120.2
unnamed: D25.A, R121.1
unnamed: PWR24.1, R121.2
unnamed: I2C24.3, R122.2
unnamed: I2C24.1, R123.2
unnamed: JP224.1, R124.2
unnamed: JP225.1, R125.2
SCL: J1.4, J2.4, J4.4, R2.1, U1.5
SCL1: J5.4, J6.4, J7.4, R8.1, U2.5
SCL2: J9.4, J10.4, J11.4, R13.1, U3.5
SCL3: J13.4, J14.4, J15.4, R18.1, U4.5
SCL4: J17.4, J18.4, J19.4, R23.1, U5.5
SCL5: J21.4, J22.4, J23.4, R28.1, U6.5
SCL6: J25.4, J26.4, J27.4, R33.1, U7.5
SCL7: J29.4, J30.4, J31.4, R38.1, U8.5
SCL8: J33.4, J34.4, J35.4, R43.1, U9.5
SCL9: J37.4, J38.4, J39.4, R48.1, U10.5
SCL10: J41.4, J42.4, J43.4, R53.1, U11.5
SCL11: J45.4, J46.4, J47.4, R58.1, U12.5
SCL12: J49.4, J50.4, J51.4, R63.1, U13.5
SCL13: J53.4, J54.4, J55.4, R68.1, U14.5
SCL14: J57.4, J58.4, J59.4, R73.1, U15.5
SCL15: J61.4, J62.4, J63.4, R78.1, U16.5
SCL16: J65.4, J66.4, J67.4, R83.1, U17.5
SCL17: J69.4, J70.4, J71.4, R88.1, U18.5
SCL18: J73.4, J74.4, J75.4, R93.1, U19.5
SCL19: J77.4, J78.4, J79.4, R98.1, U20.5
SCL20: J81.4, J82.4, J83.4, R103.1, U21.5
SCL21: J85.4, J86.4, J87.4, R108.1, U22.5
SCL22: J89.4, J90.4, J91.4, R113.1, U23.5
SCL23: J93.4, J94.4, J95.4, R118.1, U24.5
SCL24: J97.4, J98.4, J99.4, R123.1, U25.5
SDA: J1.3, J2.3, J4.3, R1.1, U1.8
SDA1: J5.3, J6.3, J7.3, R7.1, U2.8
SDA2: J9.3, J10.3, J11.3, R12.1, U3.8
SDA3: J13.3, J14.3, J15.3, R17.1, U4.8
SDA4: J17.3, J18.3, J19.3, R22.1, U5.8
SDA5: J21.3, J22.3, J23.3, R27.1, U6.8
SDA6: J25.3, J26.3, J27.3, R32.1, U7.8
SDA7: J29.3, J30.3, J31.3, R37.1, U8.8
SDA8: J33.3, J34.3, J35.3, R42.1, U9.8
SDA9: J37.3, J38.3, J39.3, R47.1, U10.8
SDA10: J41.3, J42.3, J43.3, R52.1, U11.8
SDA11: J45.3, J46.3, J47.3, R57.1, U12.8
SDA12: J49.3, J50.3, J51.3, R62.1, U13.8
SDA13: J53.3, J54.3, J55.3, R67.1, U14.8
SDA14: J57.3, J58.3, J59.3, R72.1, U15.8
SDA15: J61.3, J62.3, J63.3, R77.1, U16.8
SDA16: J65.3, J66.3, J67.3, R82.1, U17.8
SDA17: J69.3, J70.3, J71.3, R87.1, U18.8
SDA18: J73.3, J74.3, J75.3, R92.1, U19.8
SDA19: J77.3, J78.3, J79.3, R97.1, U20.8
SDA20: J81.3, J82.3, J83.3, R102.1, U21.8
SDA21: J85.3, J86.3, J87.3, R107.1, U22.8
SDA22: J89.3, J90.3, J91.3, R112.1, U23.8
SDA23: J93.3, J94.3, J95.3, R117.1, U24.8
SDA24: J97.3, J98.3, J99.3, R122.1, U25.8

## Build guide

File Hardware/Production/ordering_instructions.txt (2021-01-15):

panel size, 143x143mm
PCB thickness, 1.6mm
number of layers, 2
soldermask color, Black
silkscreen color, White
oz copper, 1oz
finish, HASL lead free
stencils, top
pcs per panel, 25
min trace width, 0.3048mm / 0.0120in
min drill size, 0.3000mm / 0.0118in

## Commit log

2021-01-19 Change IRQ to INT. Add Address label.
    [Qwiic_Differential_Pressure_Sensor-SDP31-Panel.brd, Qwiic_Differential_Pressure_Sensor-SDP31.brd, Qwiic_Differential_Pressure_Sensor-SDP31.sch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]
2021-01-20 Adding the new PROD_IDs
    [Qwiic_Differential_Pressure_Sensor-SDP31.brd, Qwiic_Differential_Pressure_Sensor-SDP31.sch]
2022-08-10 Update PROD_IDs. Delete New-Parts
    [Qwiic_Differential_Pressure_Sensor-SDP31-Panel.brd, Qwiic_Differential_Pressure_Sensor-SDP31.brd, Qwiic_Differential_Pressure_Sensor-SDP31.sch]

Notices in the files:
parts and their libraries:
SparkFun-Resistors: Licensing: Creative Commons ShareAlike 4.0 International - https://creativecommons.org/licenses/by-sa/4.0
